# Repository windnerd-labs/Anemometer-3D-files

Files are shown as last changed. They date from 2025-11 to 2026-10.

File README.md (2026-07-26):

# 3D files for the WindNerd 3D-printed anemometer

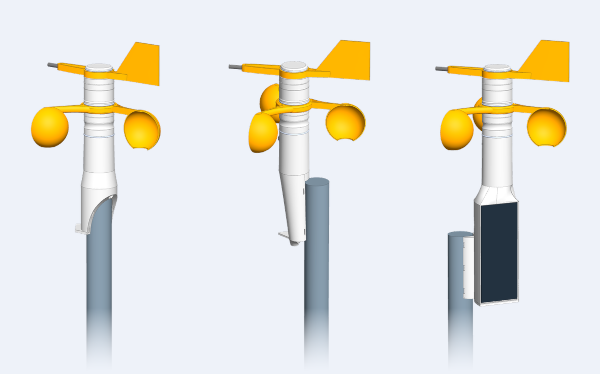
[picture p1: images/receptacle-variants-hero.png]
The anemometer head on its three receptacle variants


The WindNerd anemometer is purpose-built for 3D printing and real-world use.
This repository includes the complete set of STL files for printing your own wind meter, along with the original **FreeCAD source files** you can edit to suit your needs.

### Features

- Easy to print in **PETG**, no supports required
- Maintainable: the most exposed parts are easily replaceable
- Bearings and other [essential hardware parts](doc/BILL_OF_MATERIALS.md#small-parts) are standard, off-the-shelf parts
- No wiring or mechanical contacts, sensing is **fully magnetic** using Hall ICs on a single integrated PCB
- Can house a Wi-Fi, cellular LTE or serial sensor board
- Modular: the anemometer head fits several receptacle variants, for different mounting options or extra features such as solar power

Electronics and essential parts are [**available as kits**](https://windnerd.net/en/shop) you can complete with your own 3D prints.

## STL - 3D printing
The STL files can be opened with a slicer like UltiMaker Cura or Bambu Studio.
Check out the [printing guide](https://windnerd.net/docs/anemometer/3d-printing).

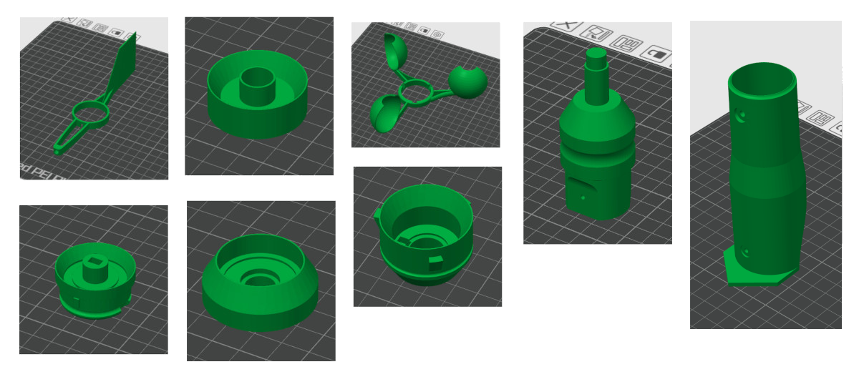
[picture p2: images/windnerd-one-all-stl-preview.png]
Preview all printed parts


## CAD (FCStd, FreeCAD)
The source files can be opened and edited with [FreeCAD](https://www.freecad.org/downloads.php), a free and open-source parametric CAD tool for Windows, Mac and Linux.

FreeCAD screenshot of the anemometer model

All files are openly licensed under [CC BY-SA 4.0](https://creativecommons.org/licenses/by-sa/4.0/)

© 2026 WindNerd.net – You are free to share and remix, even commercially, as long as you credit us and use the same license.

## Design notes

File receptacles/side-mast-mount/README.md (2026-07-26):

# 3D files for Side Mast Mount

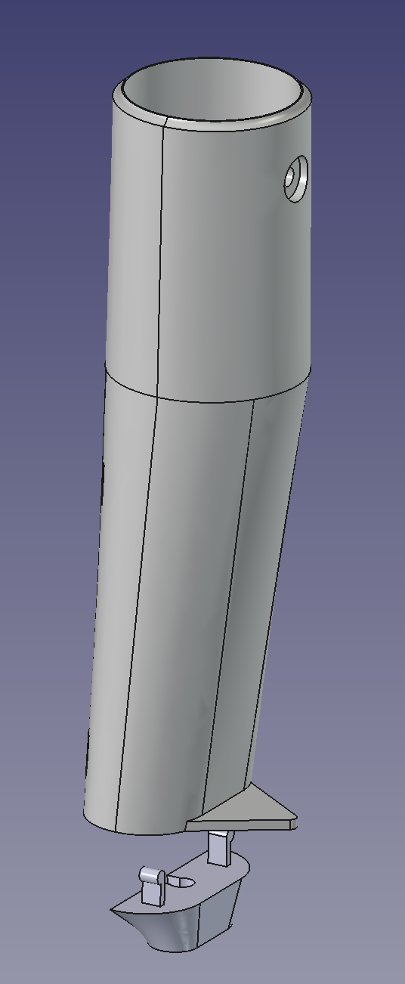
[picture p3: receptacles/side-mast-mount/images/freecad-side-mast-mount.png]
Preview Freecad Model Side Mast Mount


All files are openly licensed via [CC BY-SA 4.0](https://creativecommons.org/licenses/by-sa/4.0/)

© 2026 WindNerd.net – You are free to share and remix, even commercially, as long as you credit us and use the same license.

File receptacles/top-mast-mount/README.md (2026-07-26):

# 3D files for Top Mast Mount

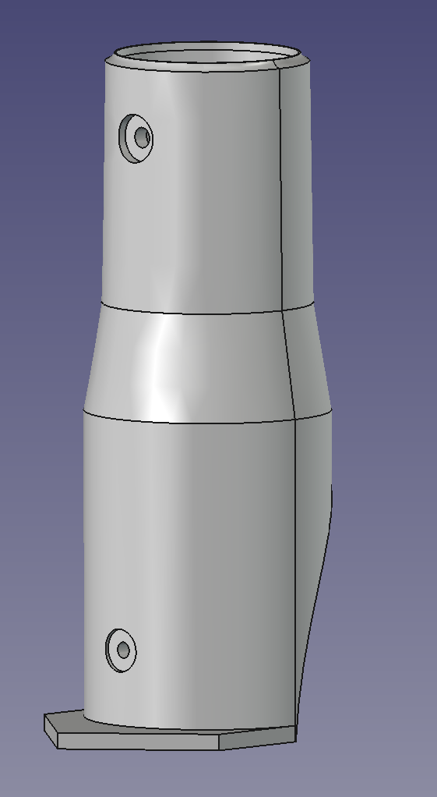
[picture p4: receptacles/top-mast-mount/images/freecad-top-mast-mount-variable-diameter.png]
Preview Freecad Model top mast mount


## Adjust dimensions for your mast

This repository includes ready-to-print files that fit the most common steel tube and pipe diameters.

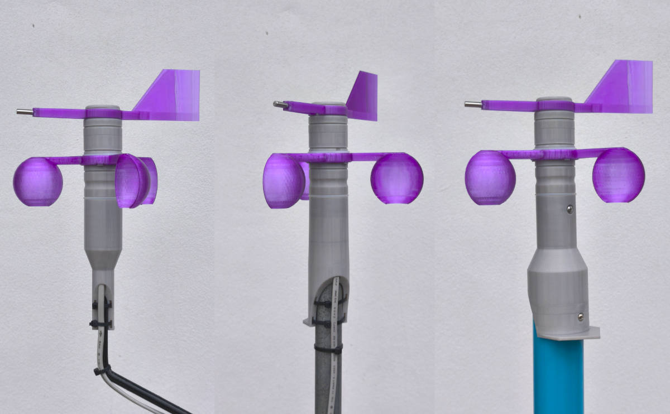
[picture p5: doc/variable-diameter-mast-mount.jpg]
Anemometer mounted on different masts


If none of the provided sizes match your requirement, you can easily generate a custom part by editing one variable in the CAD source file.

Follow these steps:

- Open **receptacles/top-mast-mount/top-mast-mount-variable-diameter.FCStd** in Freecad.
- Expand the **1-top-mast-mount** body.
- Select `Mast Mount Dimensions` variable set.
- Adjust the Mast_Diameter parameter as needed and verify the updated 3D preview.

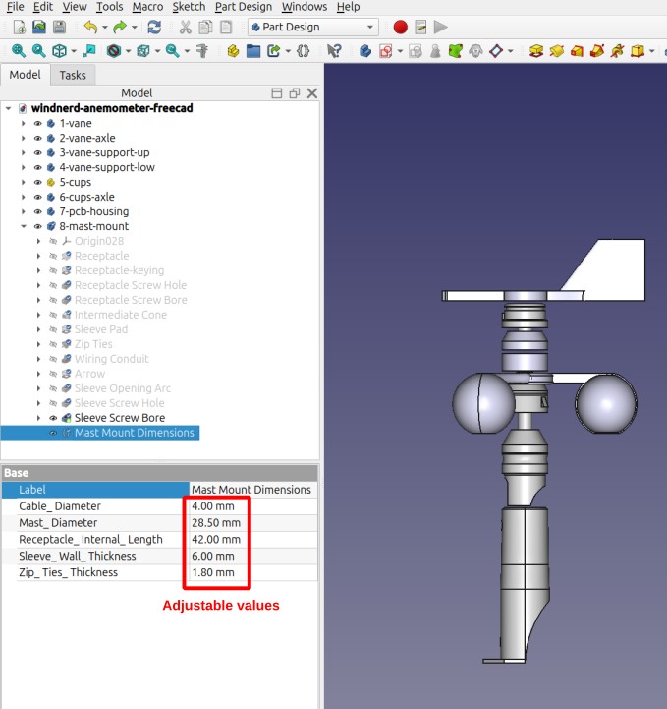
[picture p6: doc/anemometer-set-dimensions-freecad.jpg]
How to adjust mast mount dimensions


- Select **1-top-mast-mount** body
- File -> Export -> save as STL mesh

All files are openly licensed via [CC BY-SA 4.0](https://creativecommons.org/licenses/by-sa/4.0/)

© 2026 WindNerd.net – You are free to share and remix, even commercially, as long as you credit us and use the same license.

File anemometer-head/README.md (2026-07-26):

# 3D files for the WindNerd Anemometer Head

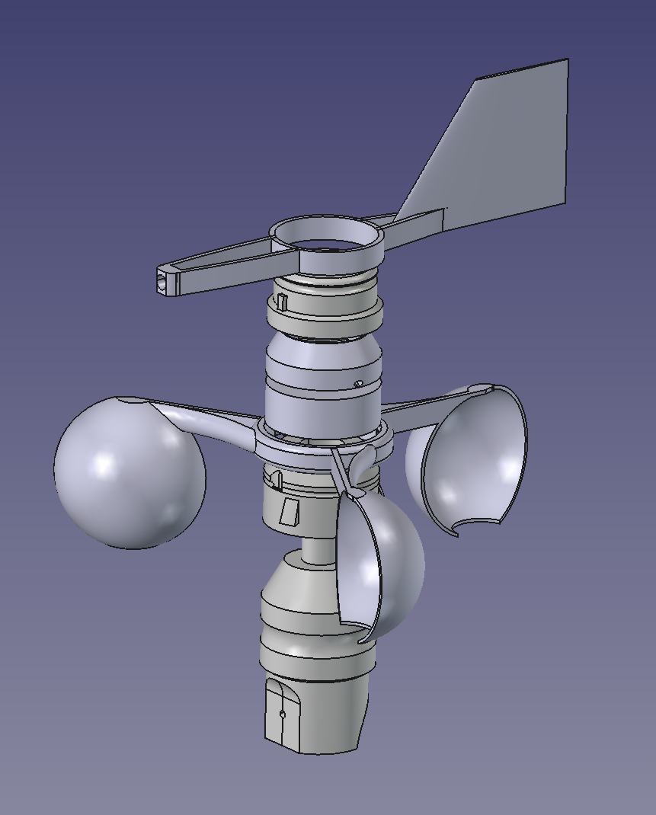
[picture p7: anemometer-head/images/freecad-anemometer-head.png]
Preview Freecad Model Anemometer Head


All files are openly licensed via [CC BY-SA 4.0](https://creativecommons.org/licenses/by-sa/4.0/)

© 2026 WindNerd.net – You are free to share and remix, even commercially, as long as you credit us and use the same license.

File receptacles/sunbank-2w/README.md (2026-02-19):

# 3D files for WindNerd Sunbank 2W

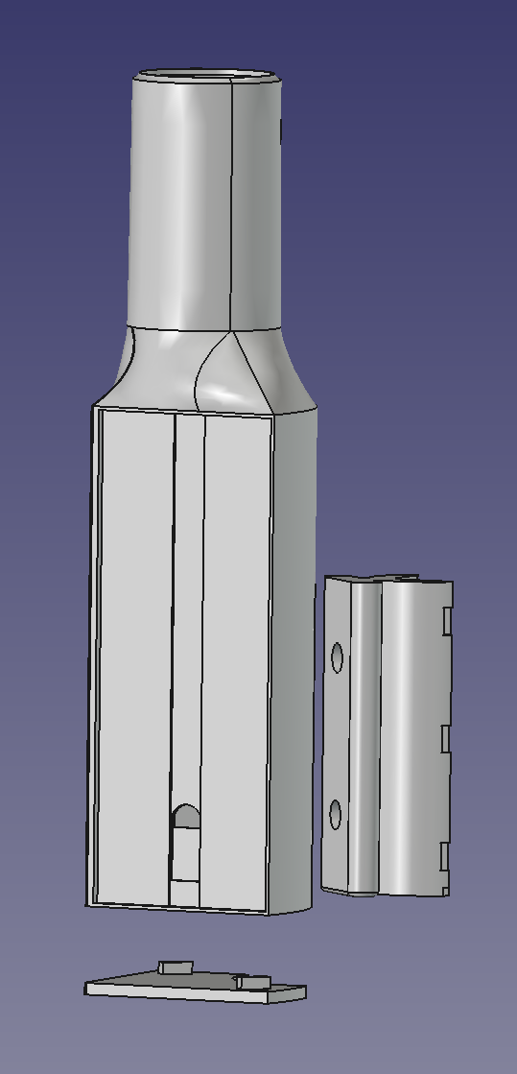
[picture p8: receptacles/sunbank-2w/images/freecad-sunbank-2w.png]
Preview Freecad Model Sunbank 2W


All files are openly licensed via [CC BY-SA 4.0](https://creativecommons.org/licenses/by-sa/4.0/)

© 2026 WindNerd.net – You are free to share and remix, even commercially, as long as you credit us and use the same license.

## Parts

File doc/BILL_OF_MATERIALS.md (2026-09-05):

# WindNerd Anemometer - Bill of Materials

## Required hardware (in addition to the 3D-printed parts)

### Small Parts
- 1 cylinder neodymium magnet 3x5 mm (for rotor)
- 1 cylinder neodymium magnet 4x6 mm (for vane)
- 1 stainless steel M5×20 mm dowel pin (vane counterweight)
- 1 silicone ring 32 mm CS 2mm
- 2 silicone rings 36 mm CS 2mm
- 1 stainless steel screw M2.5 8mm (PCB screw)
- 1 stainless steel screw M4 12mm (body screw)
- 2 6001 low friction POM/glass bearings

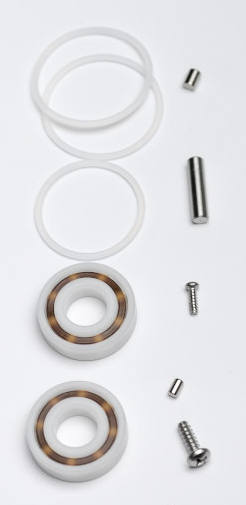
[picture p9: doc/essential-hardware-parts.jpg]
Essential parts set


### Compatible Sensor Boards

#### WindNerd Node  
ESP32C3 Wi-Fi dev board - compatible ESPHome  

#### WindNerd One-S  
Home Wi-Fi anemometer (low power) - runs on a **single lithium cell**

#### WindNerd Core  
Serial sensor and Arduino-compatible development board - certified open hardware  
[Documentation](https://github.com/windnerd-labs/Windnerd-Core)

#### WindNerd OnSpot  
Cellular LTE with [open source firmware](https://github.com/windnerd-labs/onspot-firmware)

Boards and small parts are available at [WindNerd Shop](https://windnerd.net/en/shop/)

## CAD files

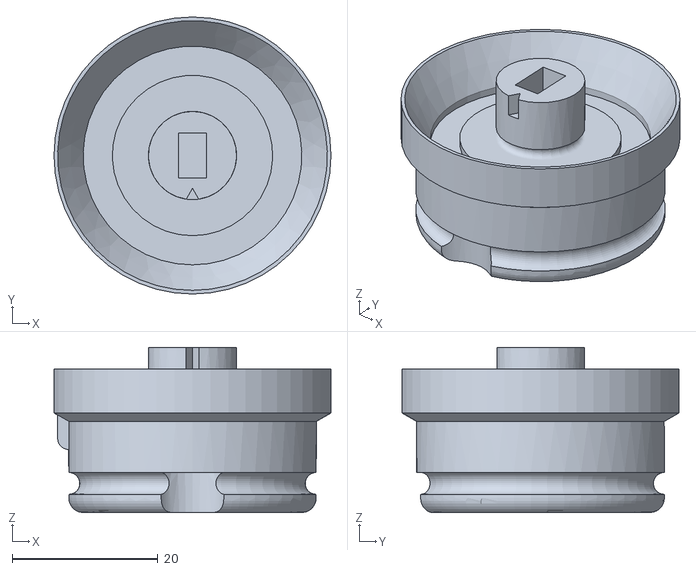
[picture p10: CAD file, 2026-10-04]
anemometer-head/2-vane-axle.stl
38.0 x 38.0 x 22.7

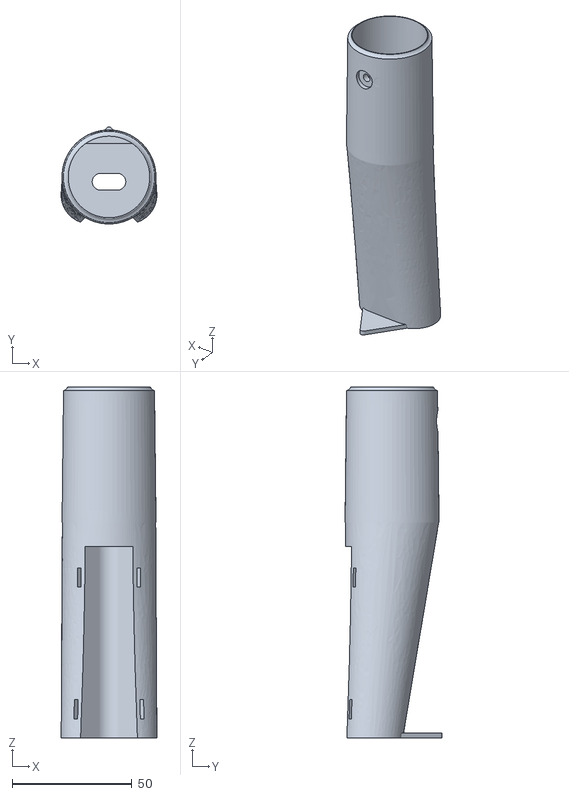
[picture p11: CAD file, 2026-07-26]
receptacles/side-mast-mount/1-side-mast-mount.stl
40.0 x 40.5 x 146.5

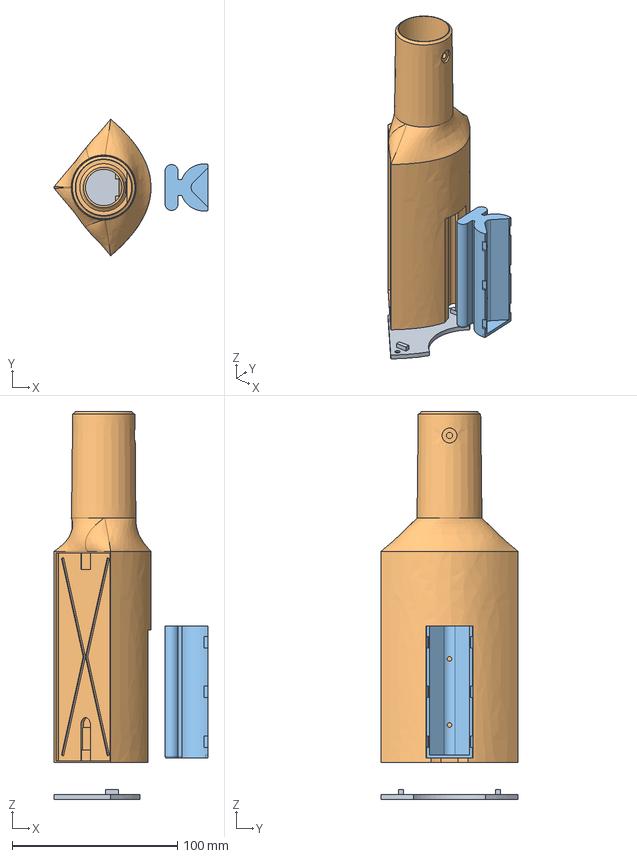
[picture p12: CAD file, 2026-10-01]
receptacles/sunbank-2w/sunbank-2w.FCStd
93.0 x 82.7 x 234.5 mm
2-bottom-cover
1-solar-body
3-dock-vgroove

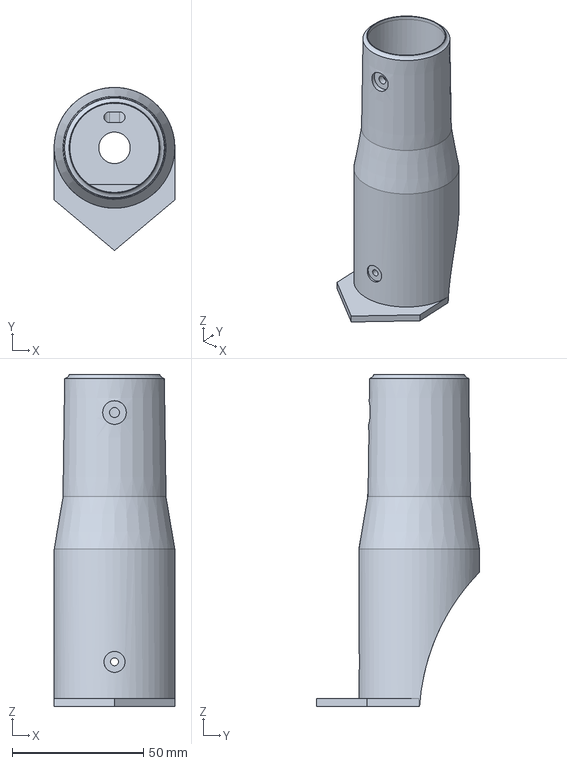
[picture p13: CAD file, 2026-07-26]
receptacles/top-mast-mount/top-mast-mount-variable-diameter.FCStd
46.0 x 62.1 x 126.5 mm

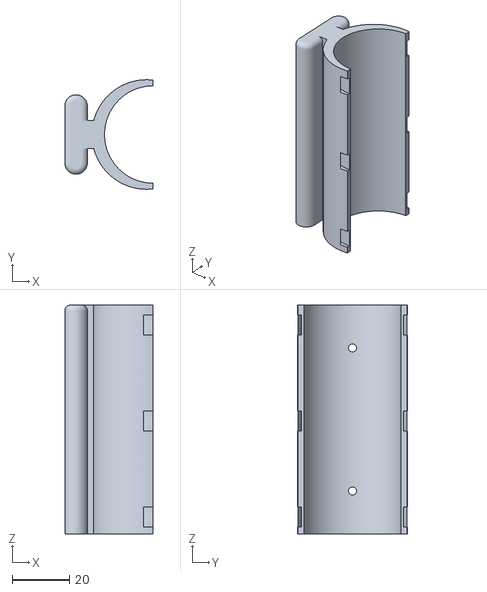
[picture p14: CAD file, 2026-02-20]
sunbank-2w/3-mast-dock-34mm.stl
30.9 x 38.3 x 80.0

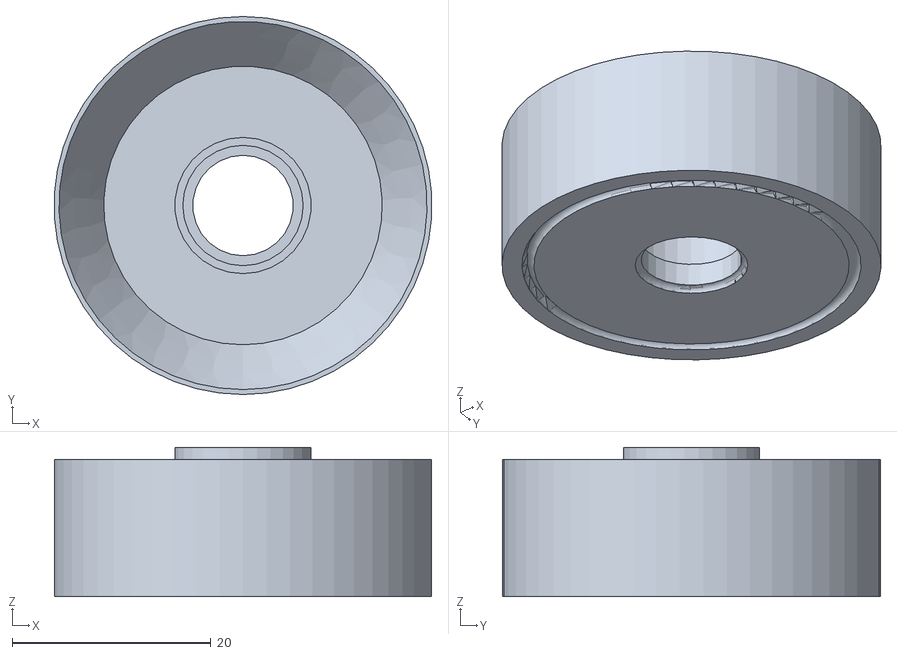
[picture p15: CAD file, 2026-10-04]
anemometer-head/4-support-low.stl
37.9 x 38.0 x 15.0

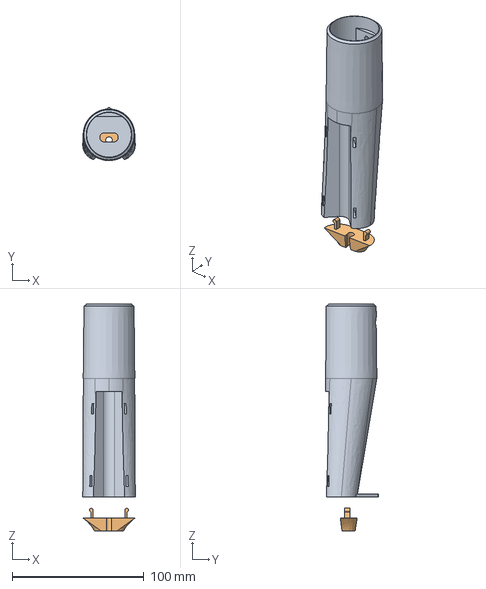
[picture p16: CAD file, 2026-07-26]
receptacles/side-mast-mount/side-mast-mount.FCStd
40.1 x 40.5 x 172.5 mm
1-side-mast-mount
2-bottom-pass through

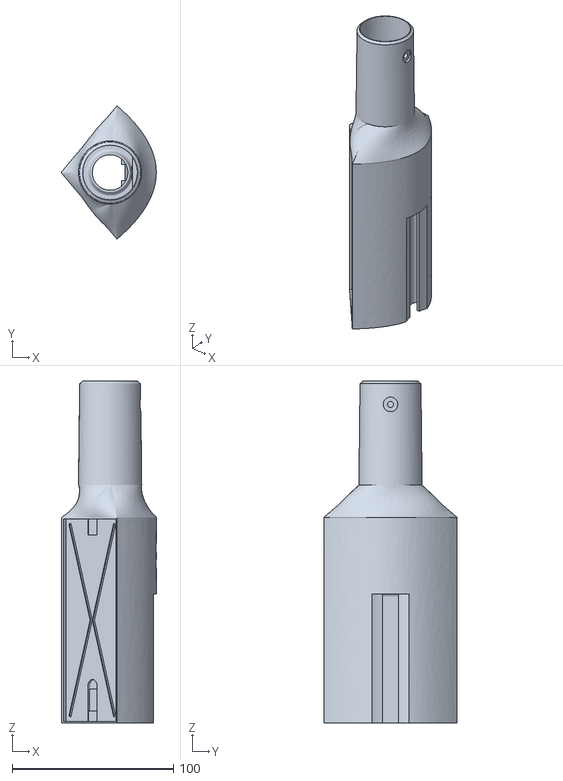
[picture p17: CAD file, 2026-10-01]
receptacles/sunbank-2w/1-solar-body.stl
58.6 x 82.7 x 212.0

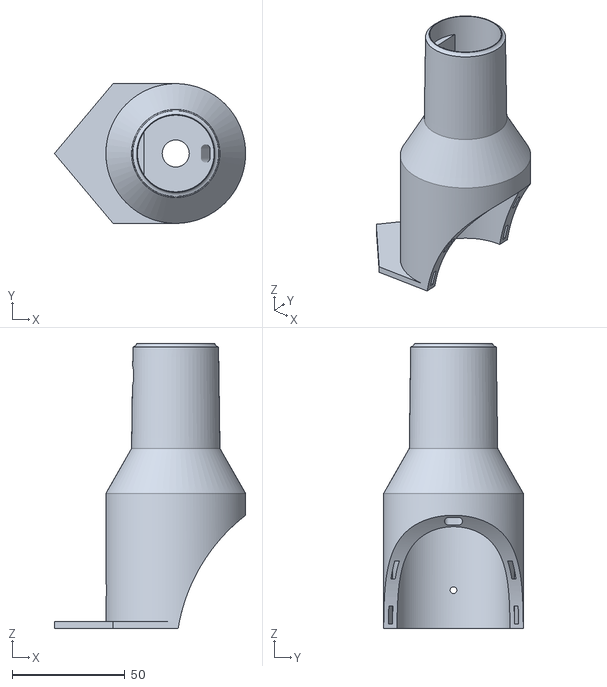
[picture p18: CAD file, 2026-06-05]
receptacles/top-mast-mount/1-top-mast-mount-50mm.stl
84.9 x 62.0 x 126.5

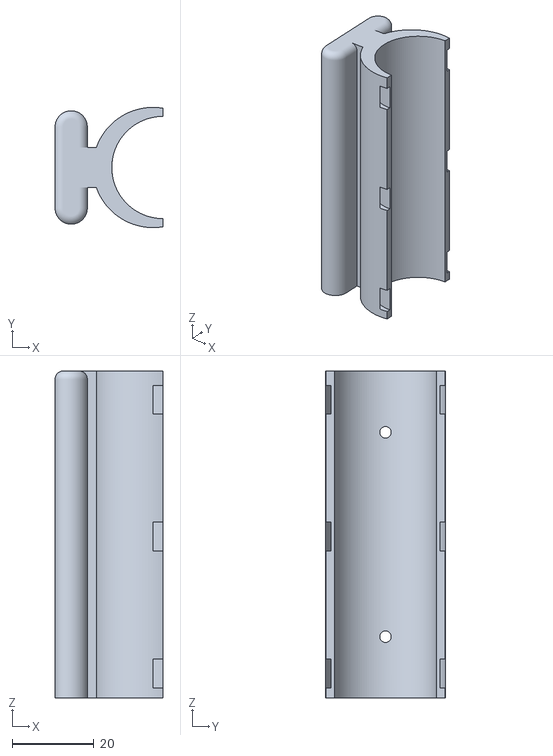
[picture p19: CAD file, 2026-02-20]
sunbank-2w/3-mast-dock-25mm.stl
26.4 x 29.4 x 80.0

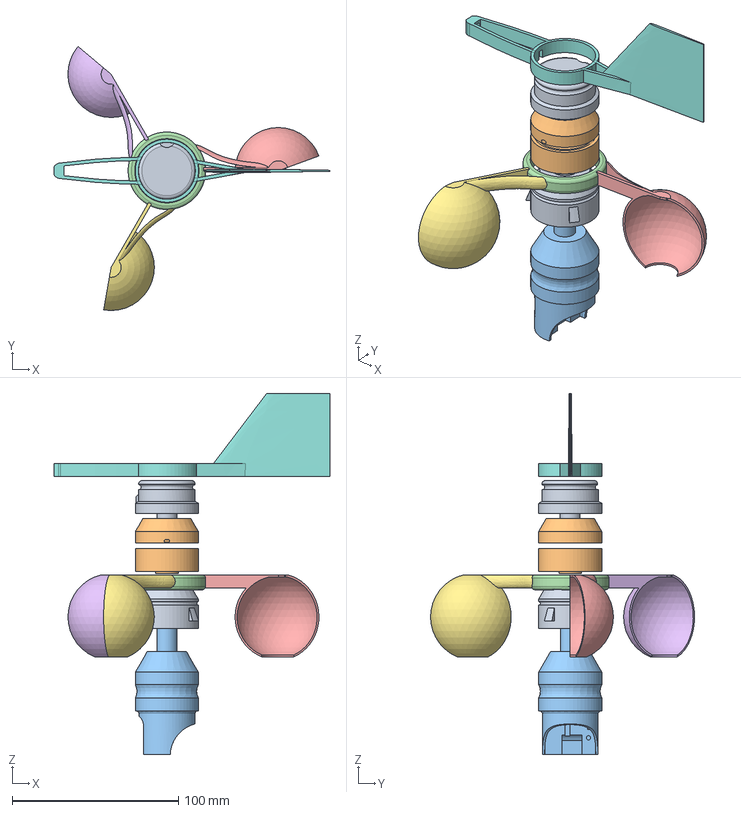
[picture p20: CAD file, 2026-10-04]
anemometer-head/anemometer-head.FCStd
165.8 x 158.8 x 217.0 mm
6-cups-axle
4-vane-support-low
7-pcb-housing
axle
Branch 1
Branch 2
Branch 3
1-vane
2-vane-axle
3-vane-support-up

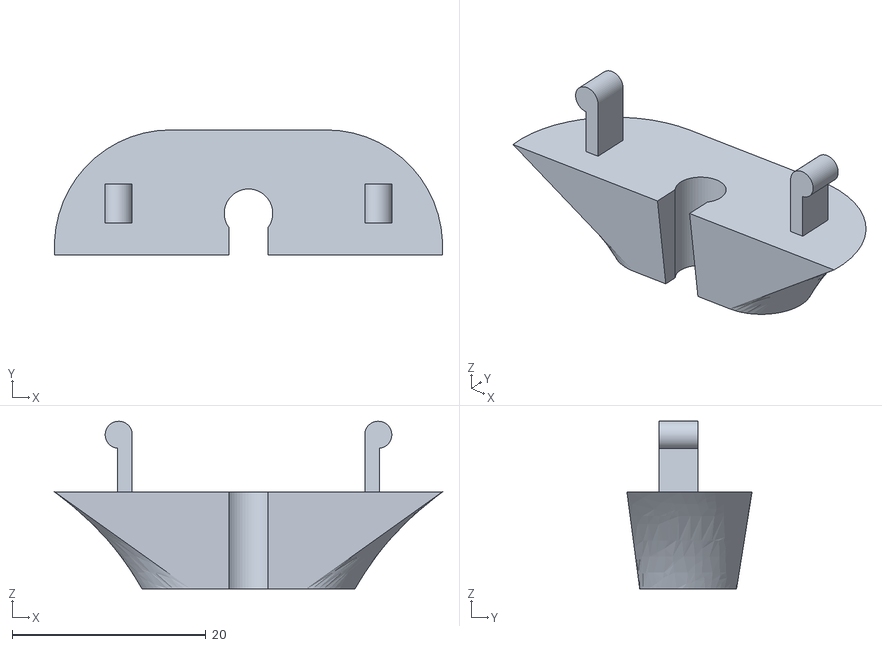
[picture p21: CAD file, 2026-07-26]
receptacles/side-mast-mount/2-bottom-pass-through.stl
40.1 x 12.9 x 17.3

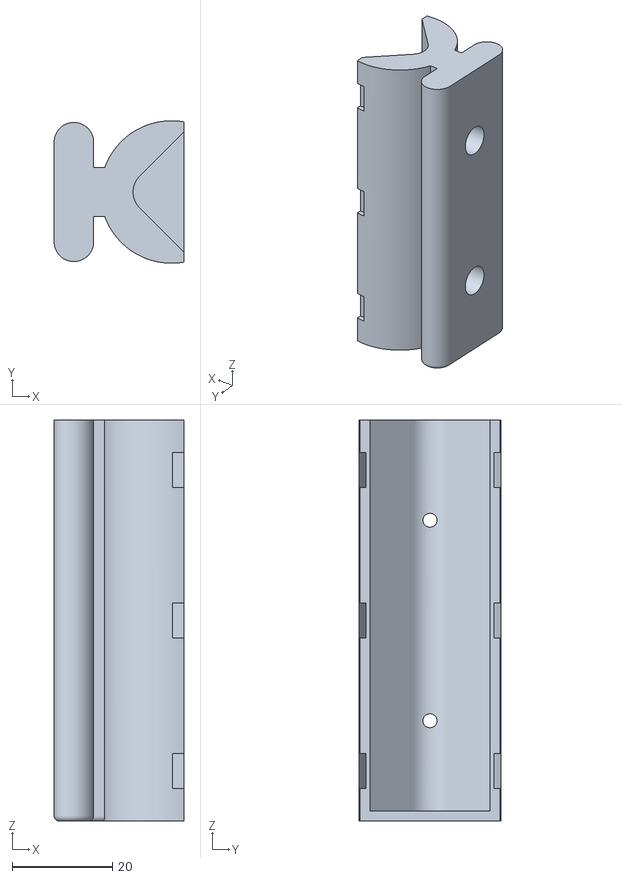
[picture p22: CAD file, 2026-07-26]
receptacles/sunbank-2w/3-dock-vgroove.stl
25.9 x 28.4 x 80.0

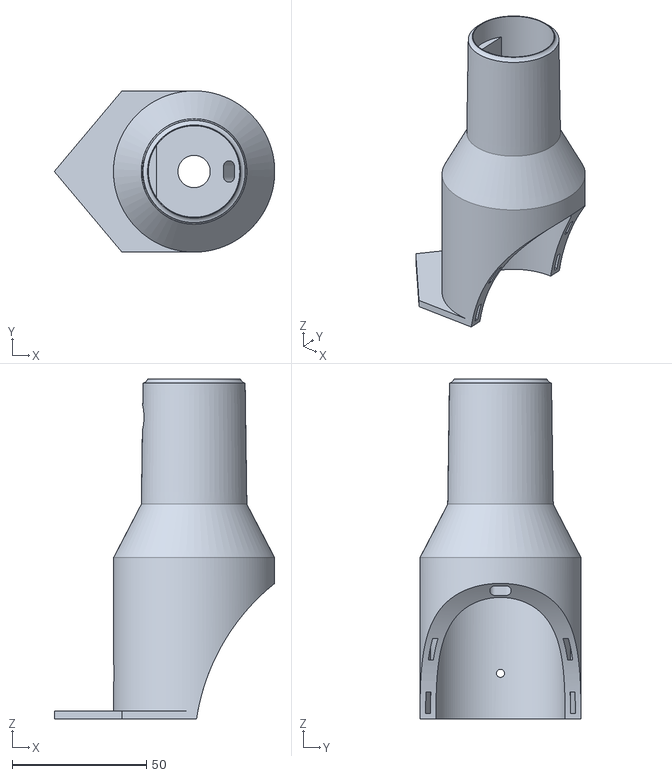
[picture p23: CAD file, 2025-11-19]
receptacles/top-mast-mount/1-top-mast-mount-48mm.stl
82.0 x 60.0 x 126.5

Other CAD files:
sunbank-2w/3-mast-dock-20mm.stl
anemometer-head/3-support-up.stl
receptacles/sunbank-2w/2-bottom-cover.stl
receptacles/top-mast-mount/1-top-mast-mount-42mm.stl
anemometer-head/1-vane-south-hemisphere.stl
anemometer-head/1-vane.stl
anemometer-head/5-cups.stl
anemometer-head/6-cups-axle.stl
anemometer-head/7-pcb-housing.stl
archives/Mast dock variable diameter up to July 2026/3-mast-dock-20mm.stl
archives/Mast dock variable diameter up to July 2026/3-mast-dock-30mm.stl
archives/Mast dock variable diameter up to July 2026/3-mast-dock-32mm.stl
archives/Mast dock variable diameter up to July 2026/3-mast-dock-40mm.stl
archives/Mast dock variable diameter up to July 2026/3-mast-dock-42mm.stl
archives/Mast dock variable diameter up to July 2026/3-mast-dock-48mm.stl
archives/Mast dock variable diameter up to July 2026/3-mast-dock-52mm.stl
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

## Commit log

2025-10-04 pockets for Core pin headers
    [7-pcb-housing.stl, windnerd-one-freecad.FCStd]
2025-11-19 archive mast mount
    [8-mast-mount.FCStd, 8-mast-mount.stl, windnerd-anemometer-freecad.FCStd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]
2025-11-19 freecad new mast mount
    [windnerd-anemometer-freecad.FCStd]
2025-11-19 adjustable mast mount
    [8-mast-mount-10mm.stl, 8-mast-mount-20mm.stl, 8-mast-mount-32mm.stl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]
2025-12-14 add water drain
    [3-support-up.stl]
2025-12-14 increase thickness above angle sensor
    [7-pcb-housing.stl]
2025-12-14 remove former mast mount from root
    [8-mast-mount.stl]
2025-12-14 water drain update
    [windnerd-anemometer-freecad.FCStd]
2026-02-19 sunbank 2W
    [1-solar-body.stl, 2-bottom-cover.stl, 3-mast-dock-20mm.stl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]
2026-02-20 3 zip ties
    [3-mast-dock-20mm.stl, 3-mast-dock-25mm.stl, 3-mast-dock-30mm.stl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]
2026-05-18 fix attachment after freecad update
    [windnerd-anemometer-freecad.FCStd]
2026-05-18 Add vane magnet polarity mark
    [2-vane-axle.stl, windnerd-anemometer-freecad.FCStd]
2026-05-28 freecad update
    [sunbank-2w.FCStd]
2026-05-28 PCB 3mm higher
    [1-solar-body.stl, sunbank-2w.FCStd]
2026-05-31 Onspot antenna connector pocket, slightly enlarge PCB conduit
    [7-pcb-housing.stl, windnerd-anemometer-freecad.FCStd]
2026-06-05 mast mount 50mm
    [8-mast-mount-50mm.stl]
2026-07-12 conduit, progressive entry
    [7-pcb-housing.stl, windnerd-anemometer-freecad.FCStd]
2026-07-21 Fix empty STL
    [7-pcb-housing.stl]
2026-07-26 side mast mount, receptacles reorg
    [1-side-mast-mount.stl, 1-solar-body.stl, 1-top-mast-mount-10mm.stl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]
2026-07-27 vane south hemisphere
    [1-vane-south-hemisphere.stl]
2026-08-26 reduce pcb screw hole diameter
    [7-pcb-housing.stl, anemometer-head.FCStd]
2026-09-05 adjust ring groove, dvane key chamfer
    [2-vane-axle.stl, 6-cups-axle.stl, anemometer-head.FCStd]
2026-10-01 Internal gutter
    [1-solar-body.stl, sunbank-2w.FCStd]
2026-10-04 add glue traps
    [2-vane-axle.stl, 3-support-up.stl, 4-support-low.stl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]
